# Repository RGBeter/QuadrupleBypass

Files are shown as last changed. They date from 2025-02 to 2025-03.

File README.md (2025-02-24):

# Quadruple Bypass
Update to the triple bypass mod for the genesis with on board mono audio, composite and S-Video generation for all models, ensuring complete functionality of the din for all genesis systems.

Also adds a ZIF connector for a future ribbon cable design to greatly simplify installation

(instructions pending, same as 3bp install except composite and mono must also be isolated from the din, and the subcarrier line must be routed to the 4bp)
### When routing the subcarrier line, make sure it's a shielded coaxial cable or twisted pair to prevent jailbars

## Model 1 Installation Guides
[Model 1 - VA1-VA6]
[Model 1 - VA7]
## Model 2 Installation Guides
[Model 2 - VA0-1.8]

[Model 2 - VA2]

[Model 2 - VA2.3]

[Model 2 - VA3]

[Model 2 - VA4]

## Model 3 Installation Guides
[Model 3 - VA1]

[Model 3 - VA2]

## Sega CDX
[CDX]

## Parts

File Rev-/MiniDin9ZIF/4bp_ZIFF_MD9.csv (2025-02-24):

Comment | Designator | Footprint | LCSC
220u | C22 | CP_EIA-3528-15_AVX-H | C122252
10u | C19,C21 | C_1206_3216Metric | C13585
0.1u | C10,C11,C12,C13,C18,C20 | C_0603_1608Metric | C14663
1u | C4,C5,C6,C7,C8,C9 | C_0603_1608Metric | C15849
10u | C2,C3 | C_0805_2012Metric | C15850
1k | R17,R30,R31 | R_0603_1608Metric | C21190
130k | R26,R29 | R_0603_1608Metric | C22795
210k | R18,R19,R20,R21,R22,R23 | R_0603_1608Metric | C22952
300k | R32,R33 | R_0603_1608Metric | C23024
330 | R35,R36 | R_0603_1608Metric | C23138
5.62k | R12,R13,R14,R15,R3,R34,R4,R5 | R_0603_1608Metric | C23188
750 | R8 | R_0603_1608Metric | C23241
100k | R25,R28,R41,R42 | R_0603_1608Metric | C25803
10k | R24,R27,R38,R39 | R_0603_1608Metric | C25804
THS7374IPWR | IC1 | TSSOP-14_4.4x5mm_P0.65mm | C2652746
150p | C14,C15 | C_0603_1608Metric | C37298
2.2k | R2,R9 | R_0603_1608Metric | C4190
75 | R10,R11,R6,R7 | R_0603_1608Metric | C4275
TL972 | IC2 | SOIC-8_3.9x4.9mm_P1.27mm | C46127
47u | C16,C17 | CP_EIA-3528-15_AVX-H | C7207
MD-90SM_MD2 | CN1 | MD90SM-MD2
SolderJumper_3_Open | D1 | SolderJumper-3_P1.3mm_Open_RoundedPad1.0x1.5mm
SolderJumper_2_Open | YR4 | SolderJumper-2
SolderJumper_2_Open | YR3 | SolderJumper-2
SolderJumper_2_Open | YR2 | SolderJumper-2
SolderJumper_2_Open | YL4 | SolderJumper-2
SolderJumper_2_Open | YL3 | SolderJumper-2
SolderJumper_2_Open | YL2 | SolderJumper-2
SolderJumper_2_Open | M1PU1 | SolderJumper-2
SolderJumper_2_Open | LPF1 | SolderJumper-2
SolderJumper_2_Open | F1 | SolderJumper-2
SolderJumper_2_Open | E1 | SolderJumper-2
SolderJumper_2_Open | C1 | SolderJumper-2
SolderJumper_2_Open | B_1 | SolderJumper-2
75 | R37 | R_0603_1608Metric
1k | R16 | R_0603_1608Metric
SolderJumper_2_Open | J4 | SolderJumper-2
511 | R43 | R_0603_1608Metric
511 | R44 | R_0603_1608Metric
511 | R40 | R_0603_1608Metric

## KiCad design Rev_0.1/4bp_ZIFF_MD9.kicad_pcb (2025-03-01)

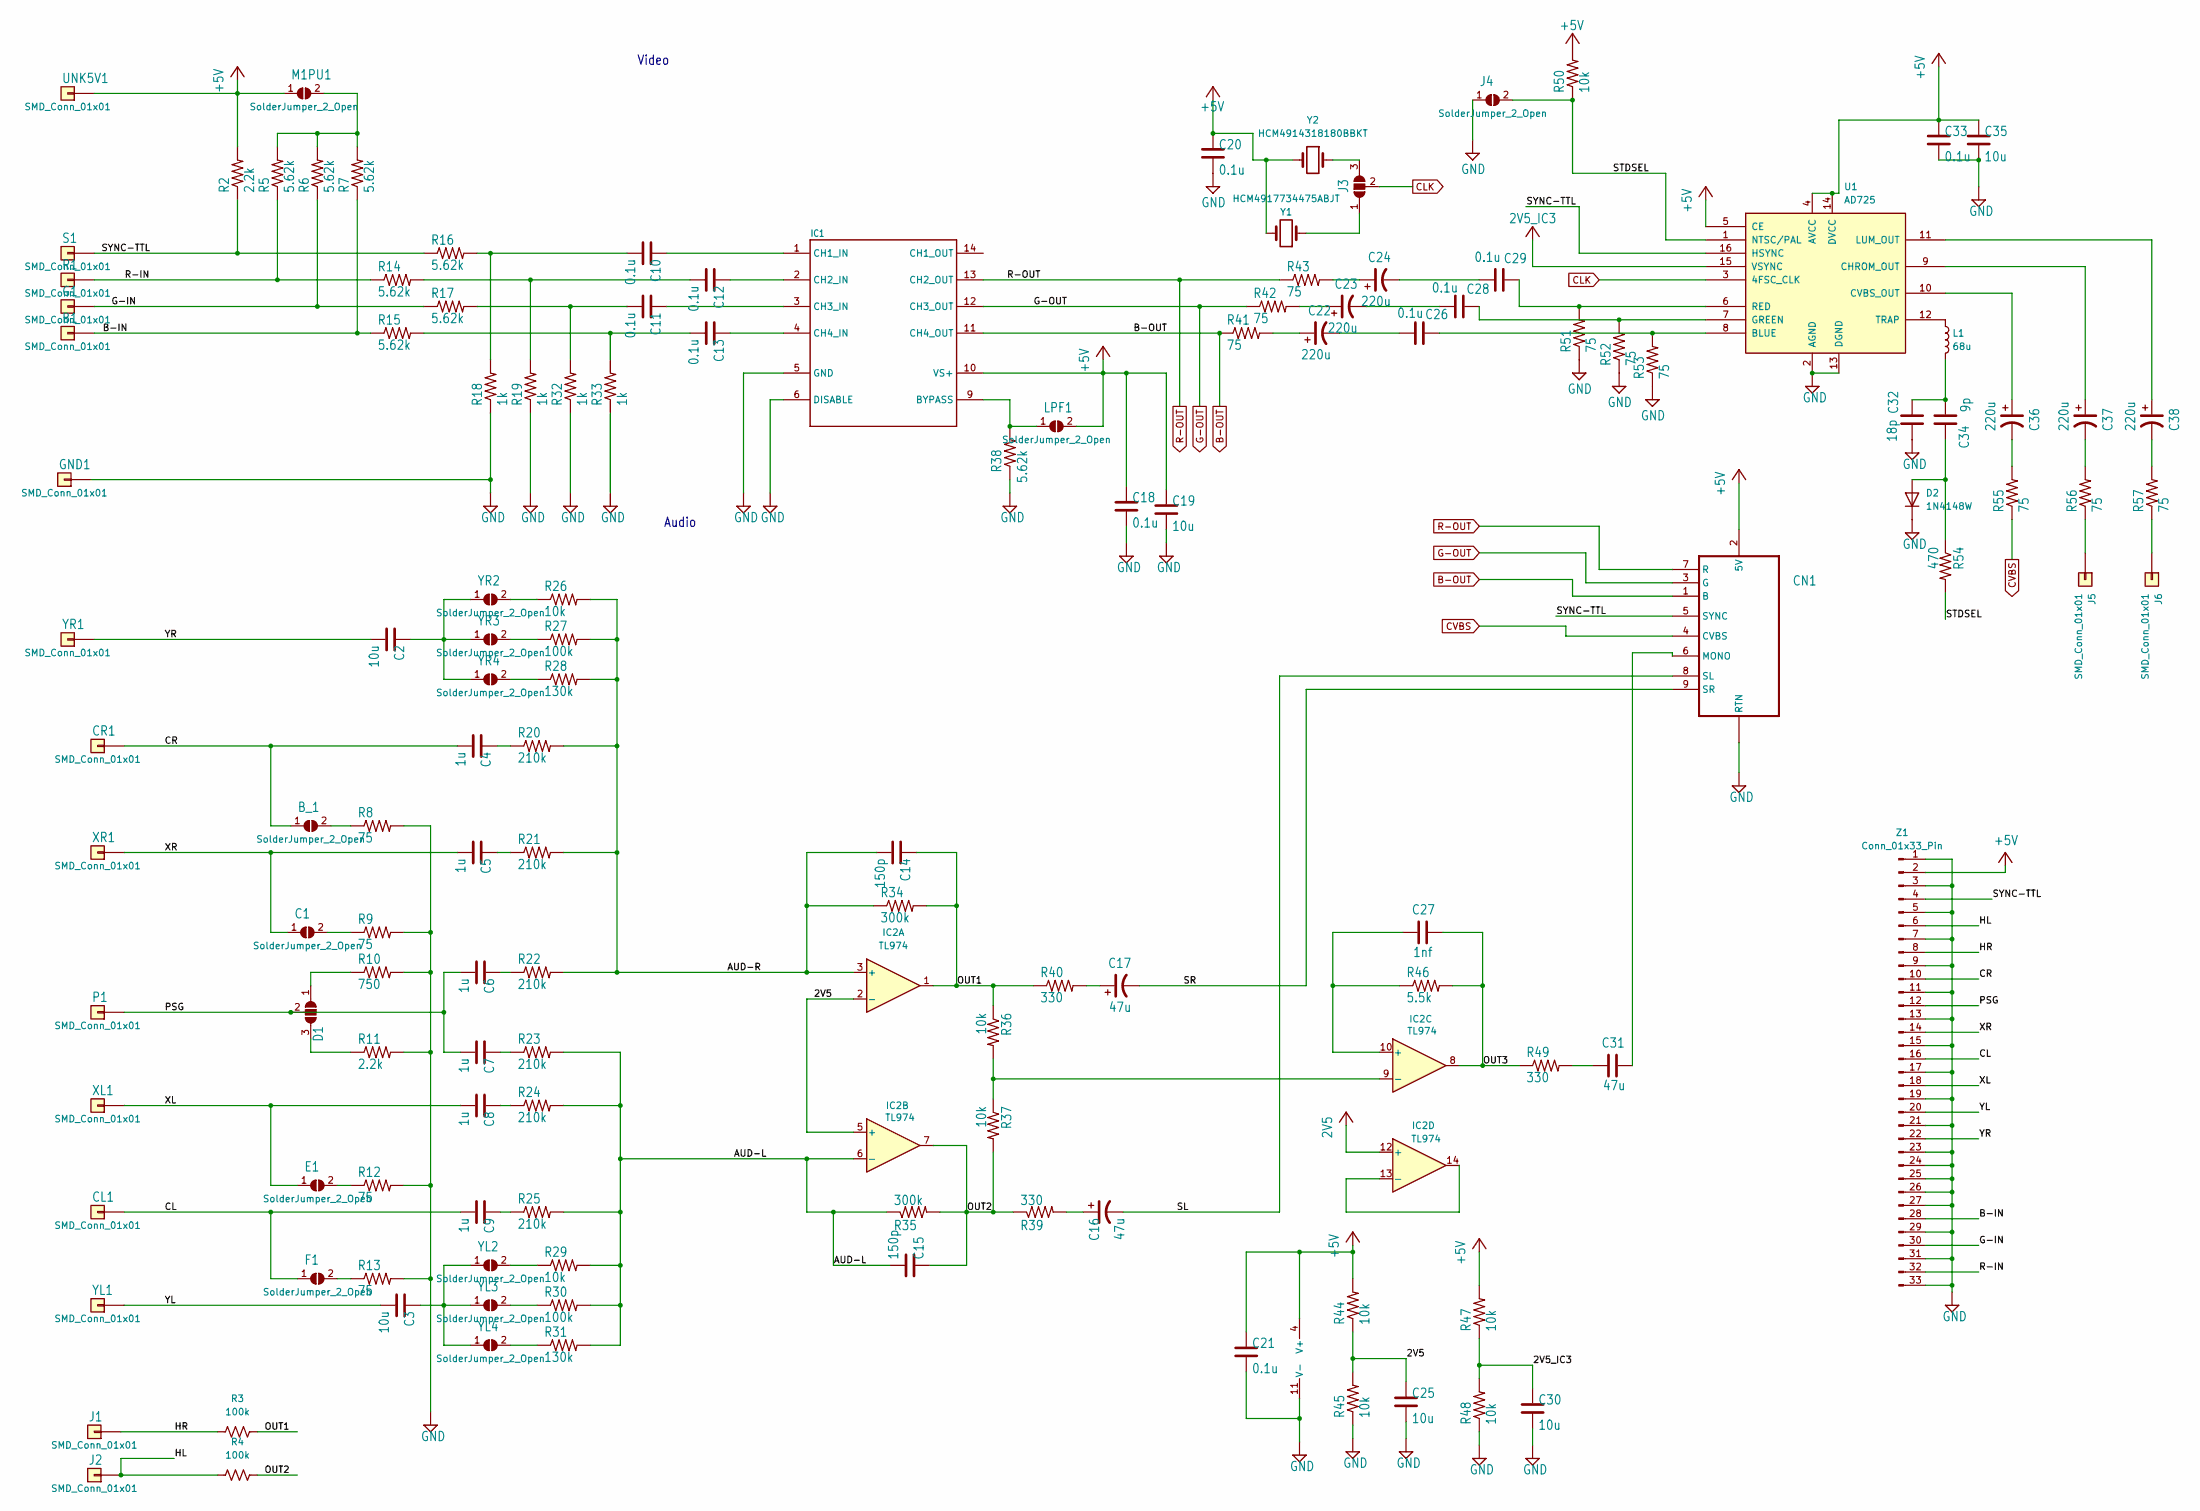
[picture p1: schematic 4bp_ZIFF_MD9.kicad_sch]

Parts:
B1: SMD_Conn_01x01; SolderWirePad_1x01_SMD_1x2mm
B_1: SolderJumper_2_Open; SolderJumper-2_P1.3mm_Open_RoundedPad1.0x1.5mm
C1: SolderJumper_2_Open; SolderJumper-2_P1.3mm_Open_RoundedPad1.0x1.5mm
C2, C3: 10u; C_0805_2012Metric
C4, C5, C6, C7, C8, C9: 1u; C_0603_1608Metric
C10, C11, C12, C13, C18, C20, C21, C26, C28, C29, C33: 0.1u; C_0603_1608Metric
C14, C15: 150p; C_0603_1608Metric
C16, C17, C31: 47u; CP_EIA-3528-15_AVX-H
C19, C25, C30, C35: 10u; C_1206_3216Metric
C22, C23, C24, C36, C37, C38: 220u; CP_EIA-3528-15_AVX-H
C27: 1nf; C_0603_1608Metric
C32: 18p; C_0603_1608Metric
C34: 9p; C_0603_1608Metric
CL1: SMD_Conn_01x01; SolderWirePad_1x01_SMD_1x2mm
CN1: MD-90SM_MD2; MD90SM-MD2
CR1: SMD_Conn_01x01; SolderWirePad_1x01_SMD_1x2mm
D1: SolderJumper_3_Open; SolderJumper-3_P1.3mm_Open_RoundedPad1.0x1.5mm
D2: 1N4148W; D_SOD-123
E1: SolderJumper_2_Open; SolderJumper-2_P1.3mm_Open_RoundedPad1.0x1.5mm
F1: SolderJumper_2_Open; SolderJumper-2_P1.3mm_Open_RoundedPad1.0x1.5mm
G1: SMD_Conn_01x01; SolderWirePad_1x01_SMD_1x2mm
GND1: SMD_Conn_01x01; SolderWirePad_1x01_SMD_1x2mm
IC1: THS7374IPWR; TSSOP-14_4.4x5mm_P0.65mm
IC2: TL974; TSSOP-14_4.4x5mm_P0.65mm
J1, J2, J5, J6: SMD_Conn_01x01; SolderWirePad_1x01_SMD_1x2mm
J3: SolderJumper_3_Open; SolderJumper-3_P1.3mm_Open_RoundedPad1.0x1.5mm
J4: SolderJumper_2_Open; SolderJumper-2_P1.3mm_Open_RoundedPad1.0x1.5mm
L1: 68u; L_0805_2012Metric
LPF1: SolderJumper_2_Open; SolderJumper-2_P1.3mm_Open_RoundedPad1.0x1.5mm
M1PU1: SolderJumper_2_Open; SolderJumper-2_P1.3mm_Open_RoundedPad1.0x1.5mm
P1: SMD_Conn_01x01; SolderWirePad_1x01_SMD_1x2mm
R1: SMD_Conn_01x01; SolderWirePad_1x01_SMD_1x2mm
R2, R11: 2.2k; R_0603_1608Metric
R3, R4, R27, R30: 100k; R_0603_1608Metric
R5, R6, R7, R14, R15, R16, R17, R38: 5.62k; R_0603_1608Metric
R8, R9, R12, R13, R41, R42, R43, R51, R52, R53, R55, R56, R57: 75; R_0603_1608Metric
R10: 750; R_0603_1608Metric
R18, R19, R32, R33: 1k; R_0603_1608Metric
R20, R21, R22, R23, R24, R25: 210k; R_0603_1608Metric
R26, R29, R36, R37, R44, R45, R47, R48, R50: 10k; R_0603_1608Metric
R28, R31: 130k; R_0603_1608Metric
R34, R35: 300k; R_0603_1608Metric
R39, R40, R49: 330; R_0603_1608Metric
R46: 5.5k; R_0603_1608Metric
R54: 470; R_0603_1608Metric
S1: SMD_Conn_01x01; SolderWirePad_1x01_SMD_1x2mm
U1: AD725; SOIC-16W_7.5x10.3mm_P1.27mm
UNK5V1: SMD_Conn_01x01; SolderWirePad_1x01_SMD_1x2mm
XL1: SMD_Conn_01x01; SolderWirePad_1x01_SMD_1x2mm
XR1: SMD_Conn_01x01; SolderWirePad_1x01_SMD_1x2mm
Y1: HCM4917734475ABJT; Crystal_SMD_HC49-SD
Y2: HCM4914318180BBKT; Crystal_SMD_HC49-SD
YL1: SMD_Conn_01x01; SolderWirePad_1x01_SMD_1x2mm
YL2, YL3, YL4: SolderJumper_2_Open; SolderJumper-2_P1.3mm_Open_RoundedPad1.0x1.5mm
YR1: SMD_Conn_01x01; SolderWirePad_1x01_SMD_1x2mm
YR2, YR3, YR4: SolderJumper_2_Open; SolderJumper-2_P1.3mm_Open_RoundedPad1.0x1.5mm
Z1: Conn_01x33_Pin; Molex_502244-3330_1x33-1MP_P0.5mm_Horizontal

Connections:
2V5: C25.1, IC2.2 (-), IC2.5 (+), IC2.12 (+), R44.1, R45.2
2V5_IC3: C30.1, R47.1, R48.2, U1.15 (VSYNC)
+5V: C18.1, C19.1, C20.1, C21.1, C33.1, C35.1, CN1.2 (5V), IC1.10 (VS+), IC2.4 (V+), LPF1.2 (B), M1PU1.1 (A), R2.2, R44.2, R47.2, R50.2, U1.4 (AVCC), U1.5 (CE), U1.14 (DVCC), UNK5V1.1, Y1.2, Y2.2, Z1.2
/AUD-L: C15.2, IC2.6 (-), R23.2, R24.2, R25.2, R29.2, R30.2, R31.2, R35.1
/AUD-R: C14.2, IC2.3 (+), R20.2, R21.2, R22.2, R26.2, R27.2, R28.2, R34.1
/B-IN: B1.1, R7.1, R15.1, Z1.28
/CL: C9.2, CL1.1, F1.1 (A), Z1.16
/CR: B_1.1 (A), C4.2, CR1.1, Z1.10
/G-IN: G1.1, R6.1, R17.1, Z1.30
/HL: J2.1, R4.1, Z1.6
/HR: J1.1, R3.1, Z1.8
/OUT1: C14.1, IC2.1, R3.2, R34.2, R36.1, R40.1
/OUT2: C15.1, IC2.7, R4.2, R35.2, R37.2, R39.1
/OUT3: C27.1, IC2.8, R46.2, R49.1
/PSG: C6.2, C7.2, D1.2 (C), P1.1, Z1.12
/R-IN: R1.1, R5.1, R14.1, Z1.32
/SL: C16.2, CN1.8 (SL)
/SR: C17.2, CN1.9 (SR)
/STDSEL: J4.2 (B), R50.1, R54.2, U1.1 (NTSC/PAL)
/SYNC-TTL: CN1.5 (SYNC), R2.1, R16.1, S1.1, U1.16 (HSYNC), Z1.4
/XL: C8.2, E1.1 (A), XL1.1, Z1.18
/XR: C1.1 (A), C5.2, XR1.1, Z1.14
/YL: C3.2, YL1.1, Z1.20
/YR: C2.2, YR1.1, Z1.22
B-OUT: CN1.1 (B), IC1.11 (CH4_OUT), R41.1
CLK: J3.2 (C), U1.3 (4FSC_CLK)
CVBS: CN1.4 (CVBS), R55.1
G-OUT: CN1.3 (G), IC1.12 (CH3_OUT), R42.1
GND: C18.2, C19.2, C20.2, C21.2, C25.2, C30.2, C32.2, C33.2, C35.2, CN1.S1 (RTN), CN1.S2 (RTN), CN1.S3 (RTN), D2.1 (K), GND1.1, IC1.5 (GND), IC1.6 (DISABLE), IC2.11 (V-), J4.1 (A), R8.2, R9.2, R10.2, R11.2, R12.2, R13.2, R18.1, R19.1, R32.1, R33.1, R38.1, R45.1, R48.1, R51.1, R52.1, R53.1, U1.2 (AGND), U1.13 (DGND), Z1.1, Z1.3, Z1.5, Z1.7, Z1.9, Z1.11, Z1.13, Z1.15, Z1.17, Z1.19, Z1.21, Z1.23, Z1.24, Z1.25, Z1.26, Z1.27, Z1.29, Z1.31, Z1.33, Z1.MP
unnamed: B_1.2 (B), R8.1
unnamed: C1.2 (B), R9.1
unnamed: C4.1, R20.1
unnamed: C5.1, R21.1
unnamed: C6.1, R22.1
unnamed: C7.1, R23.1
unnamed: C8.1, R24.1
unnamed: C9.1, R25.1
unnamed: C10.2, R16.2, R18.2
unnamed: C11.2, R17.2, R32.2
unnamed: C12.2, R14.2, R19.2
unnamed: C13.2, R15.2, R33.2
unnamed: C16.1, R39.2
unnamed: C17.1, R40.2
unnamed: C22.1, R41.2
unnamed: C22.2, C26.2
unnamed: C23.1, R42.2
unnamed: C23.2, C28.2
unnamed: C24.1, R43.2
unnamed: C24.2, C29.2
unnamed: C31.2, R49.2
unnamed: C32.1, C34.2, L1.2
unnamed: C36.2, R55.2
unnamed: C37.2, R56.2
unnamed: C38.2, R57.2
unnamed: C31.1, CN1.6 (MONO)
unnamed: D1.1 (A), R10.1
unnamed: D1.3 (B), R11.1
unnamed: C34.1, D2.2 (A), R54.1
unnamed: E1.2 (B), R12.1
unnamed: F1.2 (B), R13.1
unnamed: IC1.9 (BYPASS), LPF1.1 (A), R38.2
unnamed: C10.1, IC1.1 (CH1_IN)
unnamed: C12.1, IC1.2 (CH2_IN)
unnamed: C11.1, IC1.3 (CH3_IN)
unnamed: C13.1, IC1.4 (CH4_IN)
unnamed: C27.2, IC2.10 (+), R46.1
unnamed: IC2.9 (-), R36.2, R37.1
unnamed: IC2.13 (-), IC2.14
unnamed: J3.1 (A), Y1.1
unnamed: J3.3 (B), Y2.1
unnamed: J5.1, R56.1
unnamed: J6.1, R57.1
unnamed: M1PU1.2 (B), R5.2, R6.2, R7.2
unnamed: C26.1, R53.2, U1.8 (BLUE)
unnamed: C37.1, U1.9 (CHROM_OUT)
unnamed: C36.1, U1.10 (CVBS_OUT)
unnamed: C28.1, R52.2, U1.7 (GREEN)
unnamed: C38.1, U1.11 (LUM_OUT)
unnamed: C29.1, R51.2, U1.6 (RED)
unnamed: L1.1, U1.12 (TRAP)
unnamed: C3.1, YL2.1 (A), YL3.1 (A), YL4.1 (A)
unnamed: R29.1, YL2.2 (B)
unnamed: R30.1, YL3.2 (B)
unnamed: R31.1, YL4.2 (B)
unnamed: C2.1, YR2.1 (A), YR3.1 (A), YR4.1 (A)
unnamed: R26.1, YR2.2 (B)
unnamed: R27.1, YR3.2 (B)
unnamed: R28.1, YR4.2 (B)
R-OUT: CN1.7 (R), IC1.13 (CH2_OUT), R43.1

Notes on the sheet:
Video
Audio

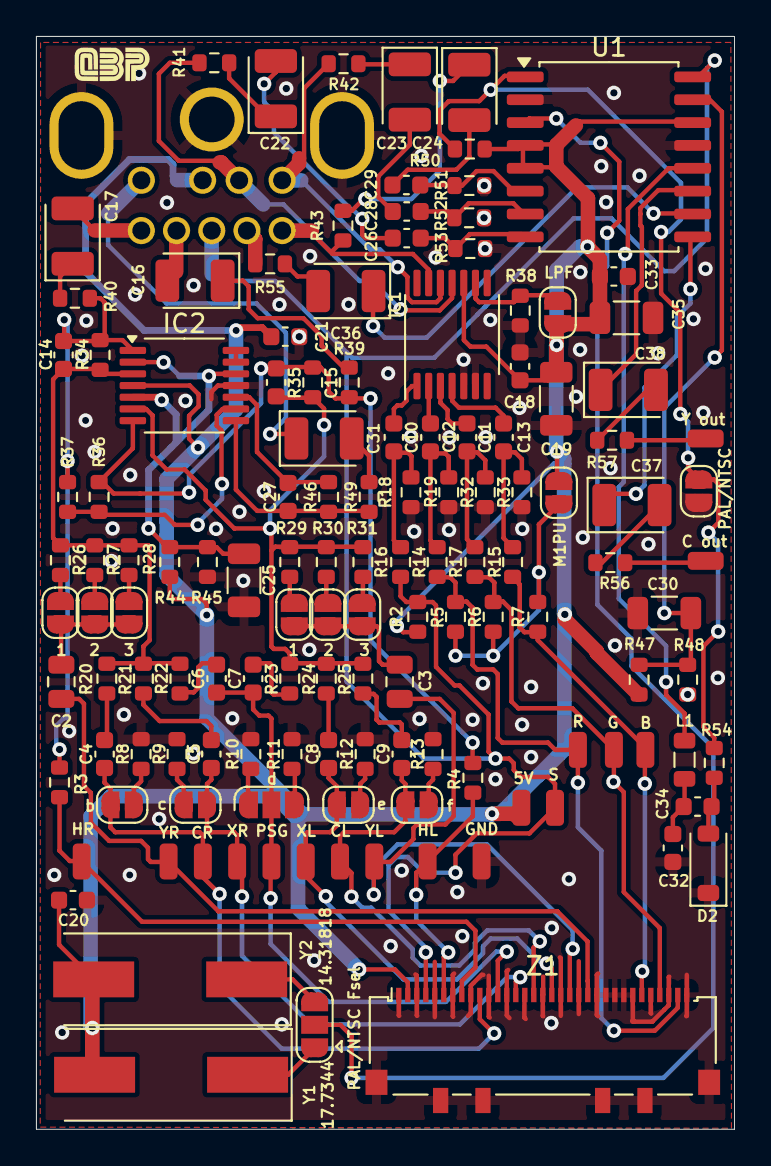
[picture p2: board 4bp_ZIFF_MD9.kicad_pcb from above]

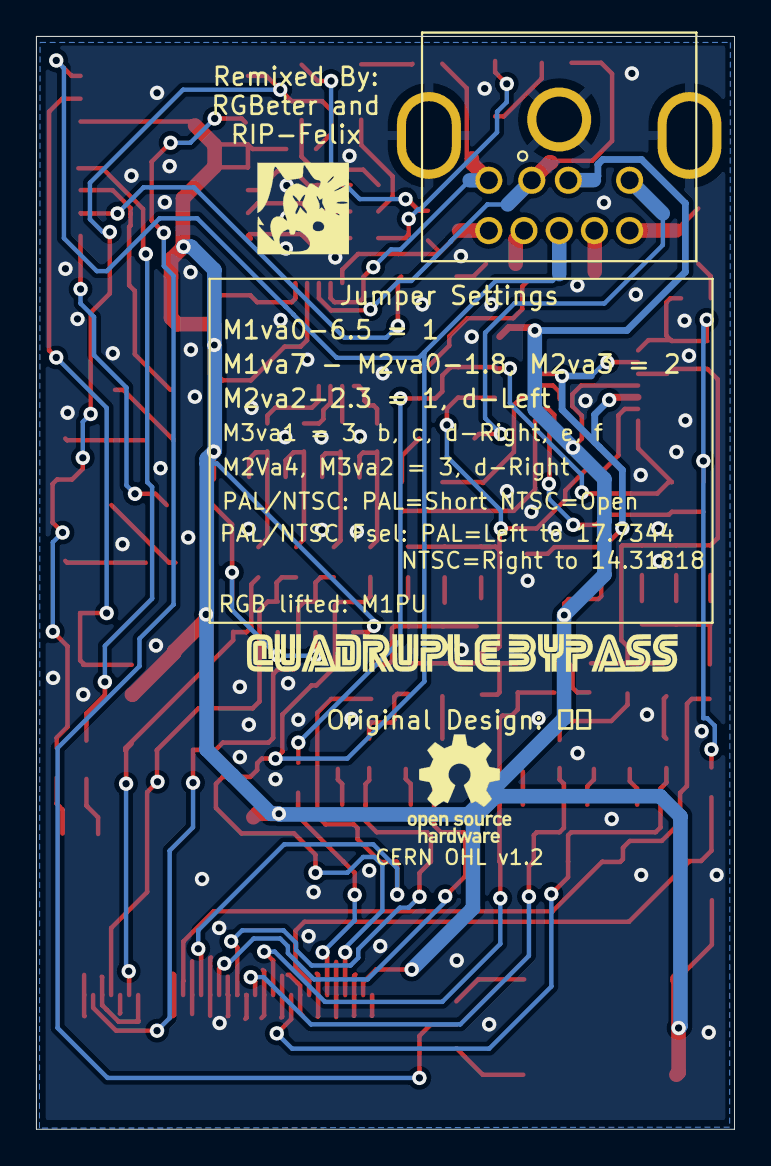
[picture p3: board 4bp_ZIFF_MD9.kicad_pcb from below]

Board: 2 copper layers, 38.8 x 60.7 mm, 136 parts (2 on the bottom side), 89 nets.

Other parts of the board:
Ref**: LOGO; QBP_LOGO
Ref**#2: LOGO; 4bp_LOGO

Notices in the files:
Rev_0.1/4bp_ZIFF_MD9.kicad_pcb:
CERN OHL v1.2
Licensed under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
